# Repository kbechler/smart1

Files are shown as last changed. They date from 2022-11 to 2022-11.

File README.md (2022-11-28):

# SmartHome - rozwiązania typu DIY

To repozytorium zawiera kilka pomysłow na rozwiąnia DIY integrujące się z Home Assistantem, Suplą i podobnymi systemami. Być może istnieją gotowce do kupienia na zagranicznych portalach aukcyjnych za niewielkie pieniądze, jednak satysfakcji ze zrobienia czegoś samodzielnie nie da się wycenić ;-)

## Co do czego?

* eagle/ - schematy i projekty płytek zrobione w Autodesk Eagle
* esphome/ - przykładowe konfiguracje dla ESPHome wykorzystujące daną płytkę

### LD-100
Prosty sterownik LEDów RGB (są tu tylko trzy kanały, więc sterować paskiem RGBW alob RGBWW się nie da) oraz WS2818 (paski LED, gdzie da się sterować każdą diodą oddzielnie). Oparty na ESP8266. Działa po WiFi z ESPHome (banalna integracja z Home Assistantem). UWAGA: Ten sterownik jest zasilany wyłącznie na 5V, więc większość popularnych taśm LED (wymagających 12V) nie będzie z nim działać.
[TODO: Zrobić próby i określić prądy, które AO3400 wytrzymują bez chłodzenia] 

### UD-100
Prosty sterownik LEDów RGBW (cztery kanały) oparty na ESP8266 oraz tranzystorach IRLR024N. Dodatkowo, zamiast czwartego kanału na płytce znalazło się miejsce dla czujnika temperatury (DS18B20) lub podczerwieni (TSOP1736). Nominalnie zasilany z 12V, więc kompatyilny z większością popularnych tasiemek LED (mono, RGB, RGBW).

## Jak to zaprogramować?

### ESP8266, ESP32
Projekty oparte na ESP8266 i ESP32 wymagają do programowania konwertera USB-RS232. Koniecznie ustawionego na 3.3V (5V może usmażyć nasze ESP) oraz programu esptool (https://github.com/espressif/esptool). Wszystkie płytki (jeżeli w opisie nie zaznaczyłem inaczej) posiadają złącze do programowania w formacie (GND-RX-TX-RST-VCC).

W najprostszej wersji używamy tylko pierwszych trzech PINów oraz "natywnego" zasilania płytki (podczas programowania chip ESP potrzebuje sporo prądu i duża część konwerterów USB-RS232 nie daje sobie z tym rady).

W wielkim skrócie i w najprostszym przypadku podłączamy trzy pierwsze PINy (czyli GND, RX, TX), naciskamy switch podpięty do portu GPIO0, podpinamy zasilanie i ruchamiamy "esphome run jakis_plik.yaml".

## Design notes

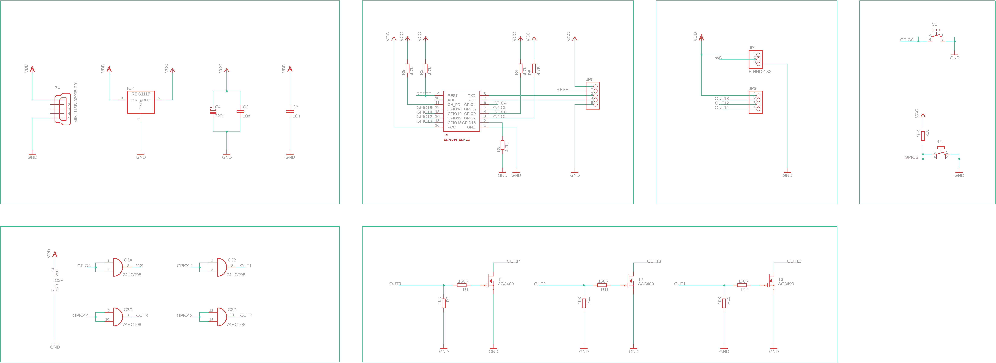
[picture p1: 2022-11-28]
eagle/ld100v1.png

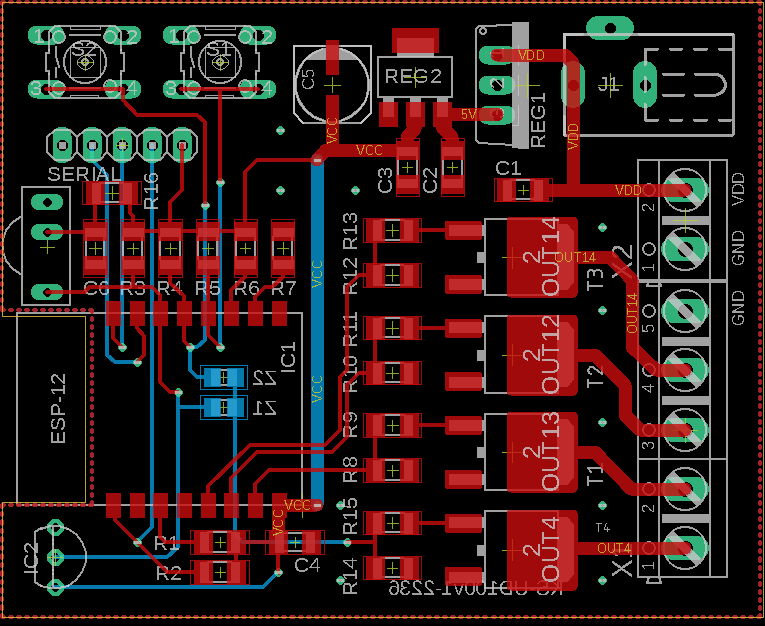
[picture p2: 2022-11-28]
eagle/ud100v1_pcb.png

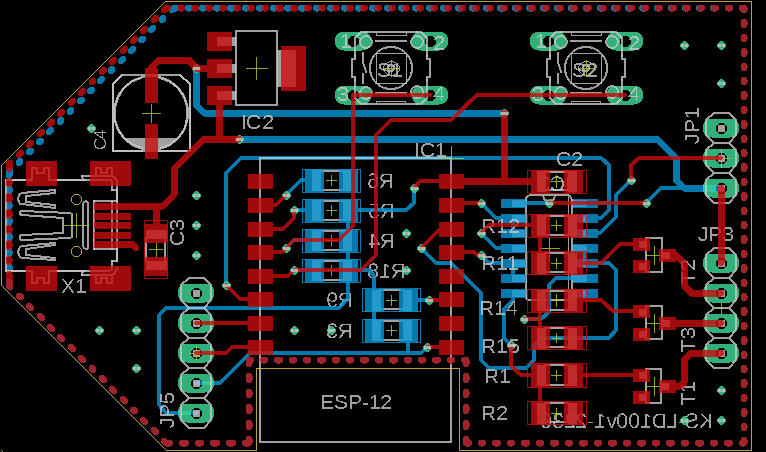
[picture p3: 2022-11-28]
eagle/ld100v1_pcb.png

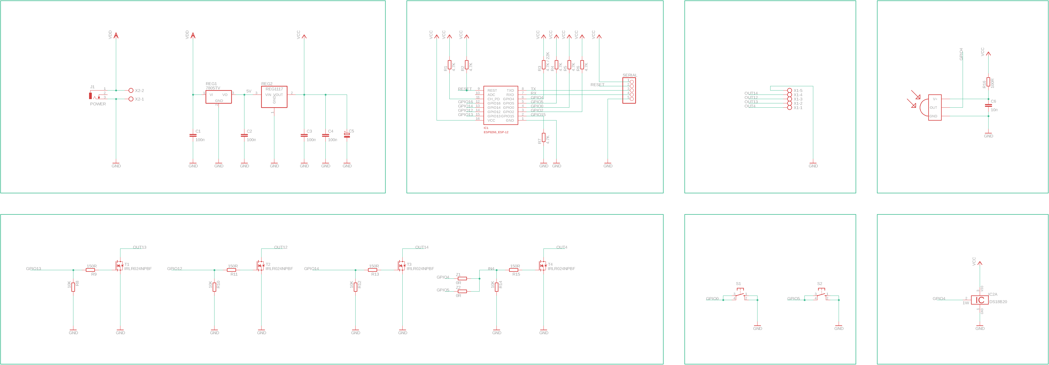
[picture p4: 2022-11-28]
eagle/ud100v1.png

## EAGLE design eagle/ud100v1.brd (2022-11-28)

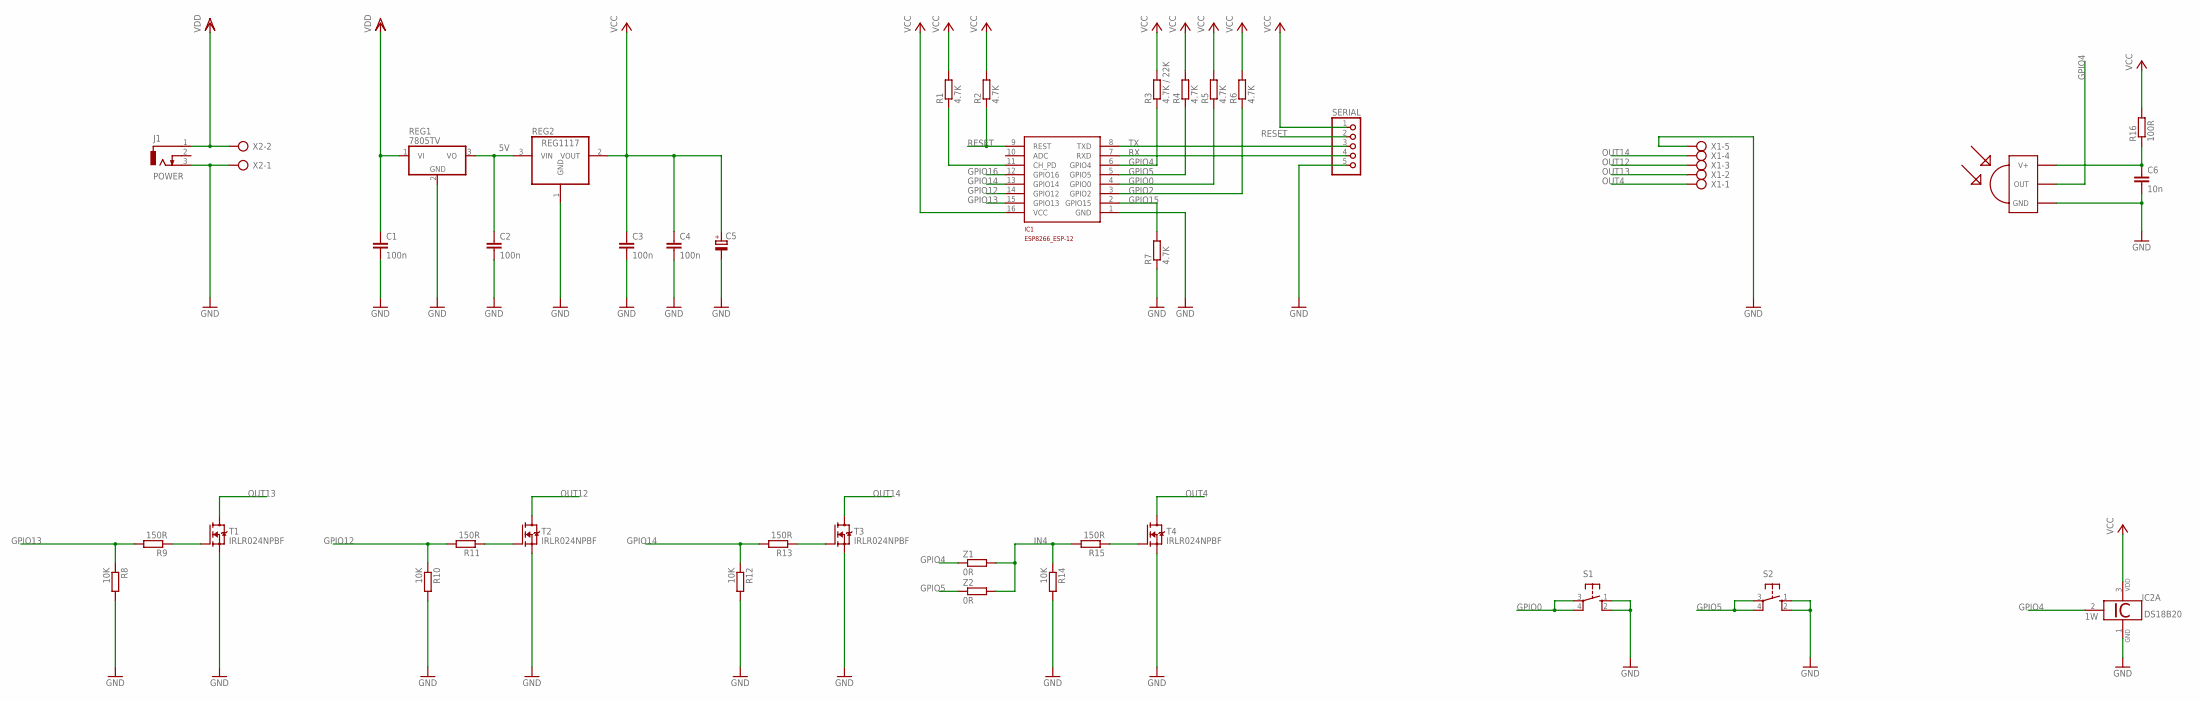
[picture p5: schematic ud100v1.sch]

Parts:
C1, C2, C3, C4: 100n; C1206
C5: CPOL-EUUD-6,3X8,8; UD-6,3X5,8_NICHICON
C6: 10n; C1206
IC1: ESP8266_ESP-12; ESP8266-ESP12
IC2: DS18B20; TO92-
J1: POWER; DCJ0303
R1, R2, R4, R5, R6, R7: 4.7K; R1206
R3: 4.7K / 22K; R1206
R8, R10, R12, R14: 10K; R1206
R9, R11, R13, R15: 150R; R1206
R16: 100R; R1206
REG1: 7805TV; TO220V
REG2: REG1117; SOT223
S1, S2: 10-XX; B3F-10XX
SERIAL: PINHD-1X5; 1X05
T1, T2, T3, T4: IRLR024NPBF; DPAK_TO252
U$1: TSOP1736; TSOP17XX
X1: AK500/5
X2: AK500/2
Z1, Z2: 0R; R0805

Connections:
5V: C2.1, REG1.3 (VO), REG2.3 (VIN)
GND: C1.2, C2.2, C3.2, C4.2, C5.-, C6.2, IC1.1 (GND), IC2.1 (GND), J1.3, R7.1, R8.2, R10.2, R12.2, R14.2, REG1.2 (GND), REG2.1 (GND), S1.1 (S), S1.2 (S1), S2.1 (S), S2.2 (S1), SERIAL.5, T1.3 (S), T2.3 (S), T3.3 (S), T4.3 (S), U$1.GND, X1.5, X2.1
GPIO0: IC1.4 (GPIO0), R5.1, S1.3, S1.4 (P1)
GPIO2: IC1.3 (GPIO2), R6.1
GPIO4: IC1.6 (GPIO4), IC2.2 (1W), R3.1, U$1.OUT, Z1.1
GPIO5: IC1.5 (GPIO5), R4.1, S2.3, S2.4 (P1), Z2.1
GPIO12: IC1.14 (GPIO12), R10.1, R11.2
GPIO13: IC1.15 (GPIO13), R8.1, R9.2
GPIO14: IC1.13 (GPIO14), R12.1, R13.2
GPIO15: IC1.2 (GPIO15), R7.2
GPIO16: IC1.12 (GPIO16)
IN4: R14.1, R15.2, Z1.2, Z2.2
unnamed: R15.1, T4.1 (G)
unnamed: IC1.11 (CH_PD), R1.1
unnamed: C6.1, R16.1, U$1.V+
unnamed: R13.1, T3.1 (G)
unnamed: R9.1, T1.1 (G)
unnamed: R11.1, T2.1 (G)
OUT4: T4.2 (D), X1.1
OUT12: T2.2 (D), X1.3
OUT13: T1.2 (D), X1.2
OUT14: T3.2 (D), X1.4
RESET: IC1.9 (REST), R2.1, SERIAL.2
RX: IC1.7 (RXD), SERIAL.4
TX: IC1.8 (TXD), SERIAL.3
VCC: C3.1, C4.1, C5.+, IC1.16 (VCC), IC2.3 (VDD), R1.2, R2.2, R3.2, R4.2, R5.2, R6.2, R16.2, REG2.2 (VOUT), SERIAL.1
VDD: C1.1, J1.1, REG1.1 (VI), X2.2

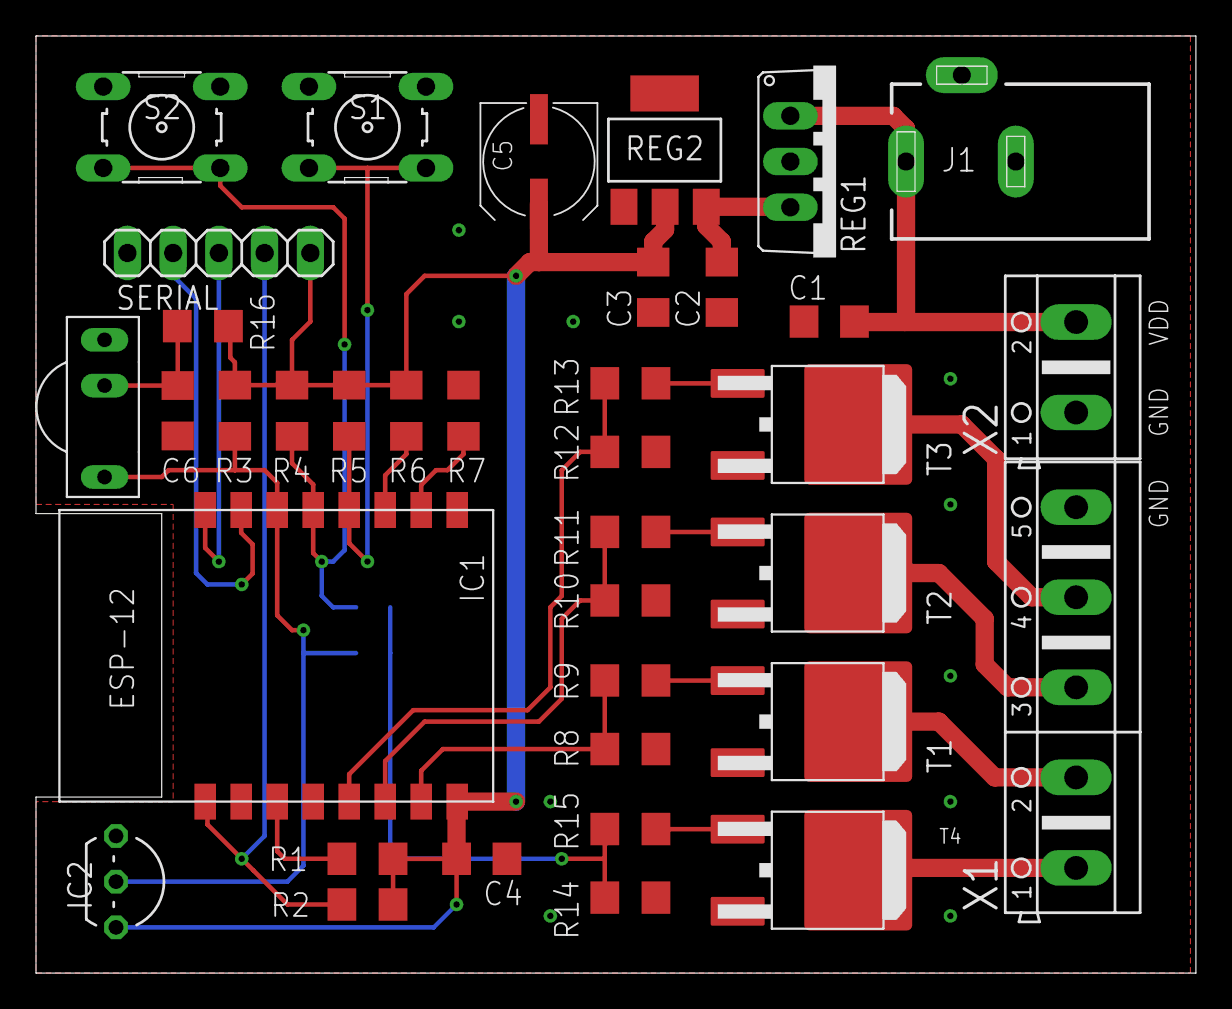
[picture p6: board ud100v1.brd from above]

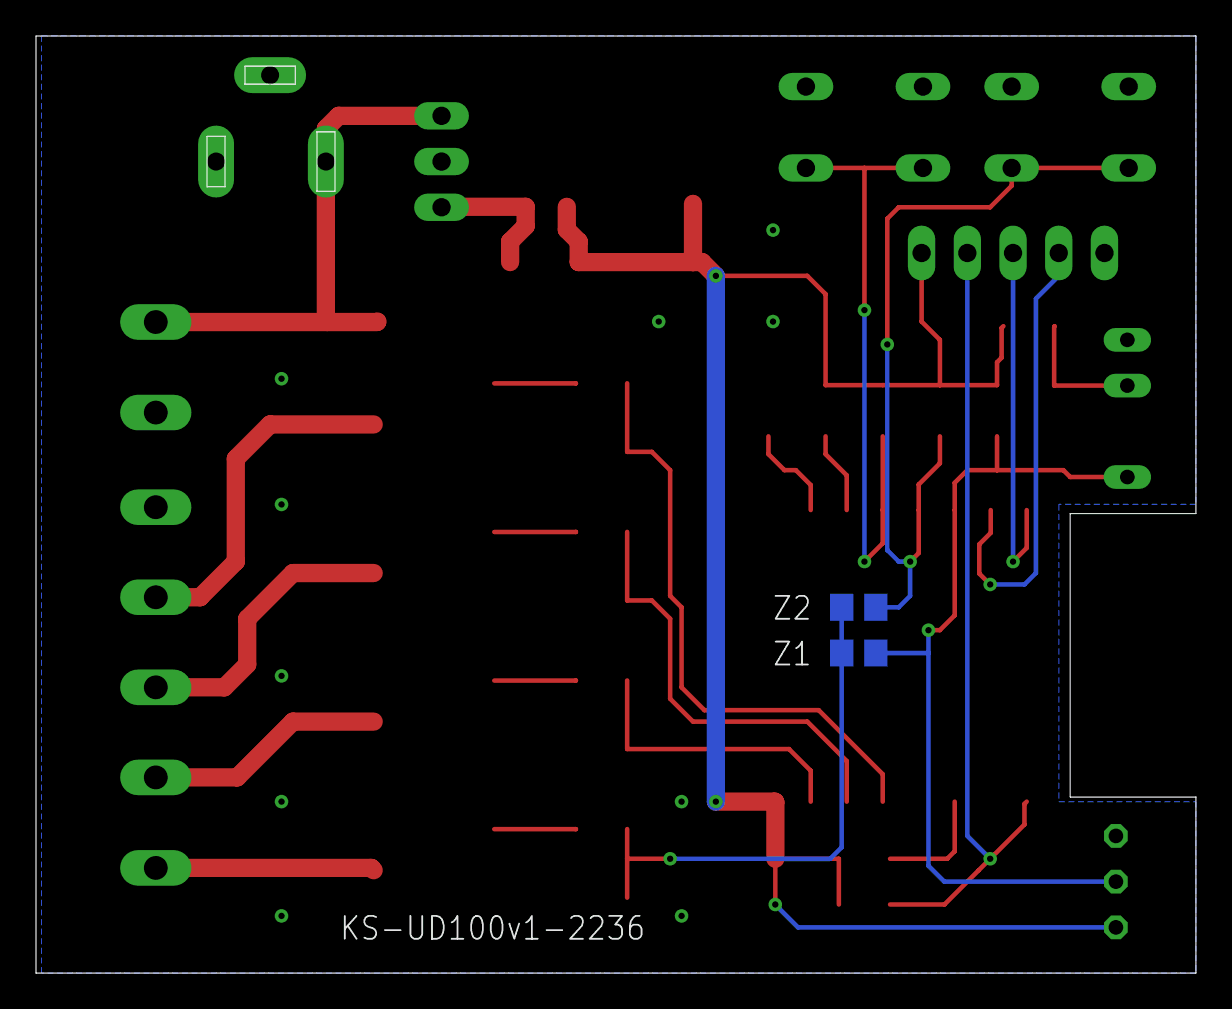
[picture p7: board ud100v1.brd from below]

Board: 2 copper layers, 64.4 x 52.1 mm, 39 parts (2 on the bottom side), 26 nets.

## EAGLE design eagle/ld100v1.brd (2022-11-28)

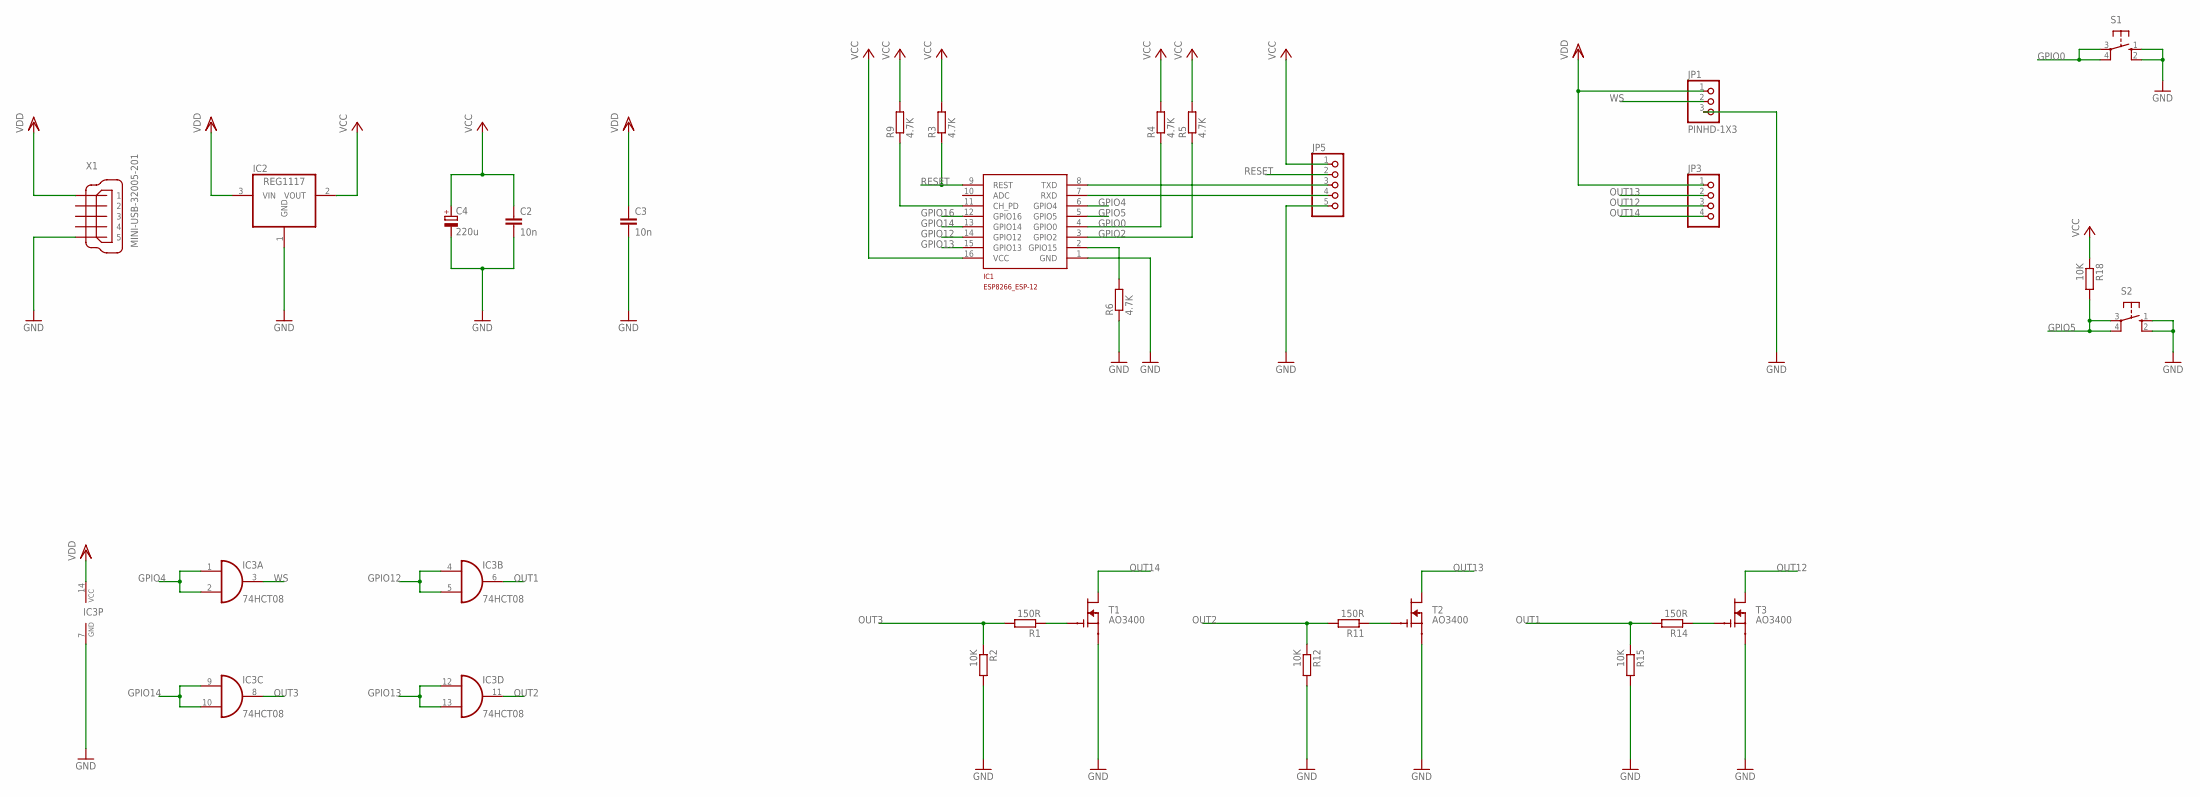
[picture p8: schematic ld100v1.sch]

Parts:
C2, C3: 10n; C1206
C4: 220u; UD-6,3X5,8_NICHICON
IC1: ESP8266_ESP-12; ESP8266-ESP12
IC2: REG1117; SOT223
IC3: 74HCT08; SO14
JP1: PINHD-1X3; 1X03
JP3: PINHD-1X4; 1X04
JP5: PINHD-1X5; 1X05
R1, R11, R14: 150R; R1206
R2, R12, R15, R18: 10K; R1206
R3, R4, R5, R6, R9: 4.7K; R1206
S1, S2: 10-XX; B3F-10XX
T1, T2, T3: AO3400; SOT23
X1: MINI-USB-32005-201; 32005-201

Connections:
GND: C2.2, C3.2, C4.-, IC1.1 (GND), IC2.1 (GND), IC3.7 (GND), JP1.3, JP5.5, R2.2, R6.1, R12.2, R15.2, S1.1 (S), S1.2 (S1), S2.1 (S), S2.2 (S1), T1.2 (S), T2.2 (S), T3.2 (S), X1.5
GPIO0: IC1.4 (GPIO0), R4.1, S1.3, S1.4 (P1)
GPIO2: IC1.3 (GPIO2), R5.1
GPIO4: IC1.6 (GPIO4), IC3.1 (I0), IC3.2 (I1)
GPIO5: IC1.5 (GPIO5), R18.2, S2.3, S2.4 (P1)
GPIO12: IC1.14 (GPIO12), IC3.4 (I0), IC3.5 (I1)
GPIO13: IC1.15 (GPIO13), IC3.12 (I0), IC3.13 (I1)
GPIO14: IC1.13 (GPIO14), IC3.9 (I0), IC3.10 (I1)
GPIO16: IC1.12 (GPIO16)
unnamed: IC1.8 (TXD), JP5.3
unnamed: IC1.7 (RXD), JP5.4
unnamed: IC1.11 (CH_PD), R9.1
unnamed: IC1.2 (GPIO15), R6.2
unnamed: R1.1, T1.1 (G)
unnamed: R11.1, T2.1 (G)
unnamed: R14.1, T3.1 (G)
OUT1: IC3.6 (O), R14.2, R15.1
OUT2: IC3.11 (O), R11.2, R12.1
OUT3: IC3.8 (O), R1.2, R2.1
OUT12: JP3.3, T3.3 (D)
OUT13: JP3.2, T2.3 (D)
OUT14: JP3.4, T1.3 (D)
RESET: IC1.9 (REST), JP5.2, R3.1
VCC: C2.1, C4.+, IC1.16 (VCC), IC2.2 (VOUT), JP5.1, R3.2, R4.2, R5.2, R9.2, R18.1
VDD: C3.1, IC2.3 (VIN), IC3.14 (VCC), JP1.1, JP3.1, X1.1
WS: IC3.3 (O), JP1.2

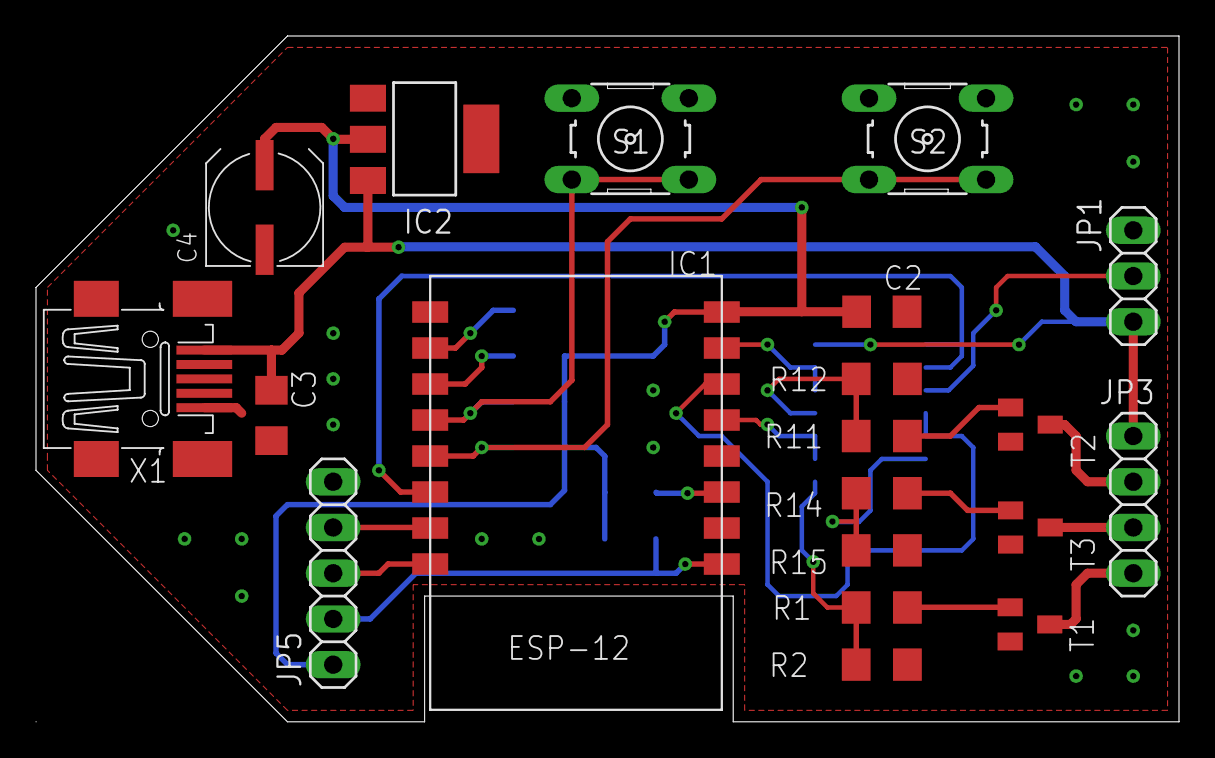
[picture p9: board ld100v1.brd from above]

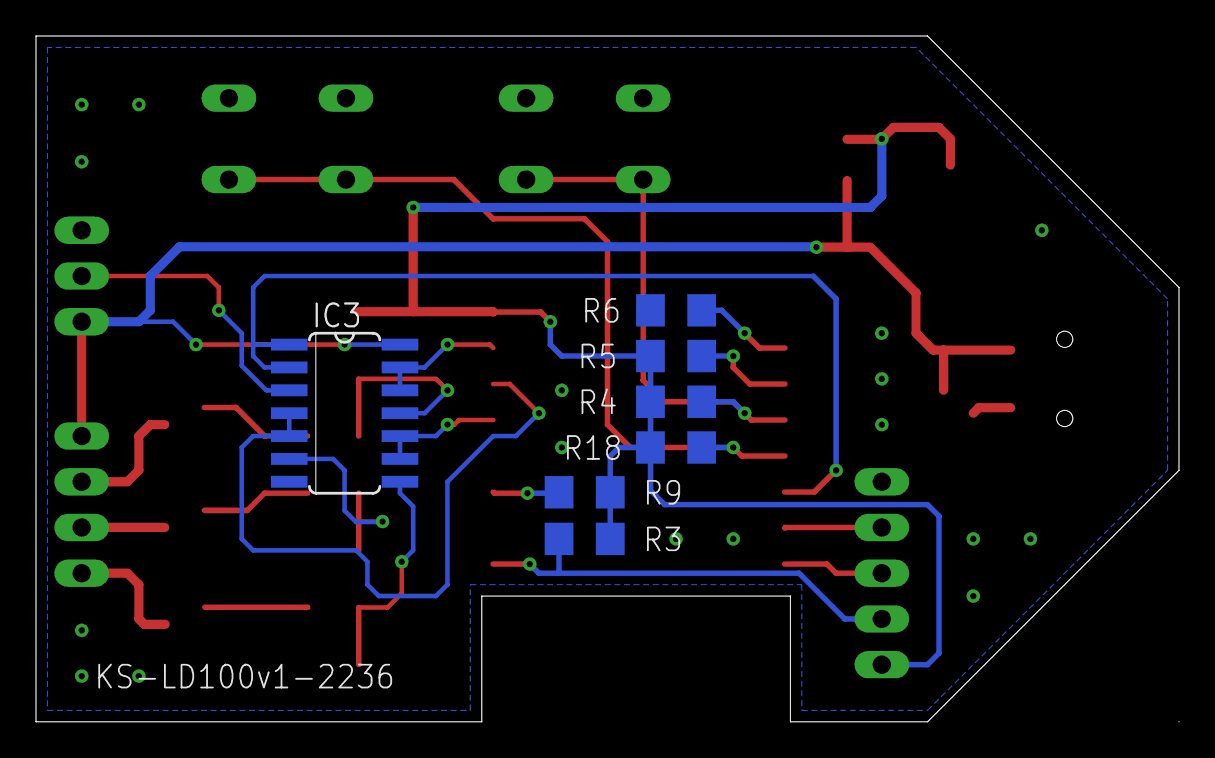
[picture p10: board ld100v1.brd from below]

Board: 2 copper layers, 63.5 x 38.1 mm, 27 parts (7 on the bottom side), 25 nets.
